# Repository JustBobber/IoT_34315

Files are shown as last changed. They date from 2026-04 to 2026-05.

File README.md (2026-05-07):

# Kom i gang med projektet

## Forudsætninger

- Python 3.3 eller nyere (tjek med `python --version` eller `python3 --version`)

---

## Opsætning af webserver

### 1. Klon projektet

```bash
git clone https://github.com/JustBobber/IoT_34315
cd IoT_34315
```

### 2. Opret virtuelt miljø

```bash
python3 -m venv .venv
```

### 3. Aktivér miljøet

**macOS / Linux:**
```bash
source .venv/bin/activate
```

**Windows:**
```bash
.venv\Scripts\activate
```

Du kan se at miljøet er aktivt når terminalen viser `(.venv)` foran din prompt.

### 4. Installér afhængigheder

```bash
pip install -r requirements.txt
```

## Opsætning af ESP'er
De to ESP'er skal have installeret firmware. Filerne ligger i ./firmware/esp/ESP8266_disp og ./firmware/esp/ESP32S3-Nano_controller til ESP8266 og ESP32S3 hhv.

### Installer firmware til ESP8266
Inden installation af firmwaren, kan det være nødvendigt at disconnecte RX-TX linket mellem ESP32 og ESP8266.
Åben filen ./firmware/esp/ESP8266_disp/ESP8266_disp.ino i Arduino IDE og installer den på ESP8266'eren.

Husk at forbind TX-RX linket igen hvis det er disconnected.

### Installer firmware til ESP32S3-Nano

Åben filen ./firmware/esp/ESP8266_disp/ESP32S3-Nano_controller.ino i Arduino IDE 
Opdater linje 45-48 til wifi netværk, password og serverens ip addresse:
```
/*
* Sørg for at starte serveren for at modtage og se dataene på localhost:5050.
*/
const char* WIFI_SSID = "<wifi name>";				    // update ssid
const char* WIFI_PASSWORD = "<wifi password>";			// update pw
const char* SERVER_BASE_URL = "http://<...ip...:5050";	// update ip
```
Når netværks instillernge er sat, installer koden på ESP32'eren.

---

# Daglig brug
For at køre projektet er der to ting du skal have kørende: webappen og ESP'erne.
Webappen står for backed og frontend. Der modtager data fra ESP, logger det i database og laver en hjemmeside hvor dataen kan ses.

ESP'erne står indsamler og sender data til webappen når en træning session er i gang. Ellers poller den serveren for at 
tjekke om der er en user logget ind da dette er et krav for at kunne påbegynde en træningssession. 

## Start server, webapp og populer database

### Aktiver virtual environment
Hver gang du åbner en ny terminal skal du aktivere miljøet igen:

```bash
source .venv/bin/activate   # macOS / Linux
.venv\Scripts\activate      # Windows
```

### Start webappen
```bash
python3 src/app.py
```
besøg siden: localhost:5050

Deaktivér venv når du er færdig:

```bash
deactivate
```

---

### Populer databasen: 
For at få noget data i databasen kør følgende script:

```bash
python3 src/seeds/alice_and_bob_seed.py
```
Det tilføjer et par users og generere et par sessions og noget data. 
Det kan køres flere gange hvis der ønskes mere data. 

### Slet databasen:
Det kan være nødvendigt/rart at slette database (training.db) den ligger her: src/training.db
```bash
rm src/training.db
```
Kør derefter seed scriptet igen for at få data i databasen.

---

## Start ESP's
Forbind det to ESP'er til power. 
OLED displayet skulle gerne vise teksten: 'GenStraek' 
og ToF sensoren skulle meget gerne gå i gang med at kalibrere ved at køre håndtaget op og derefter ned.
Hvis det er tilfældet, så bør det hele være sat op korrekt og klar til at blive brugt.

# Circuit diagram
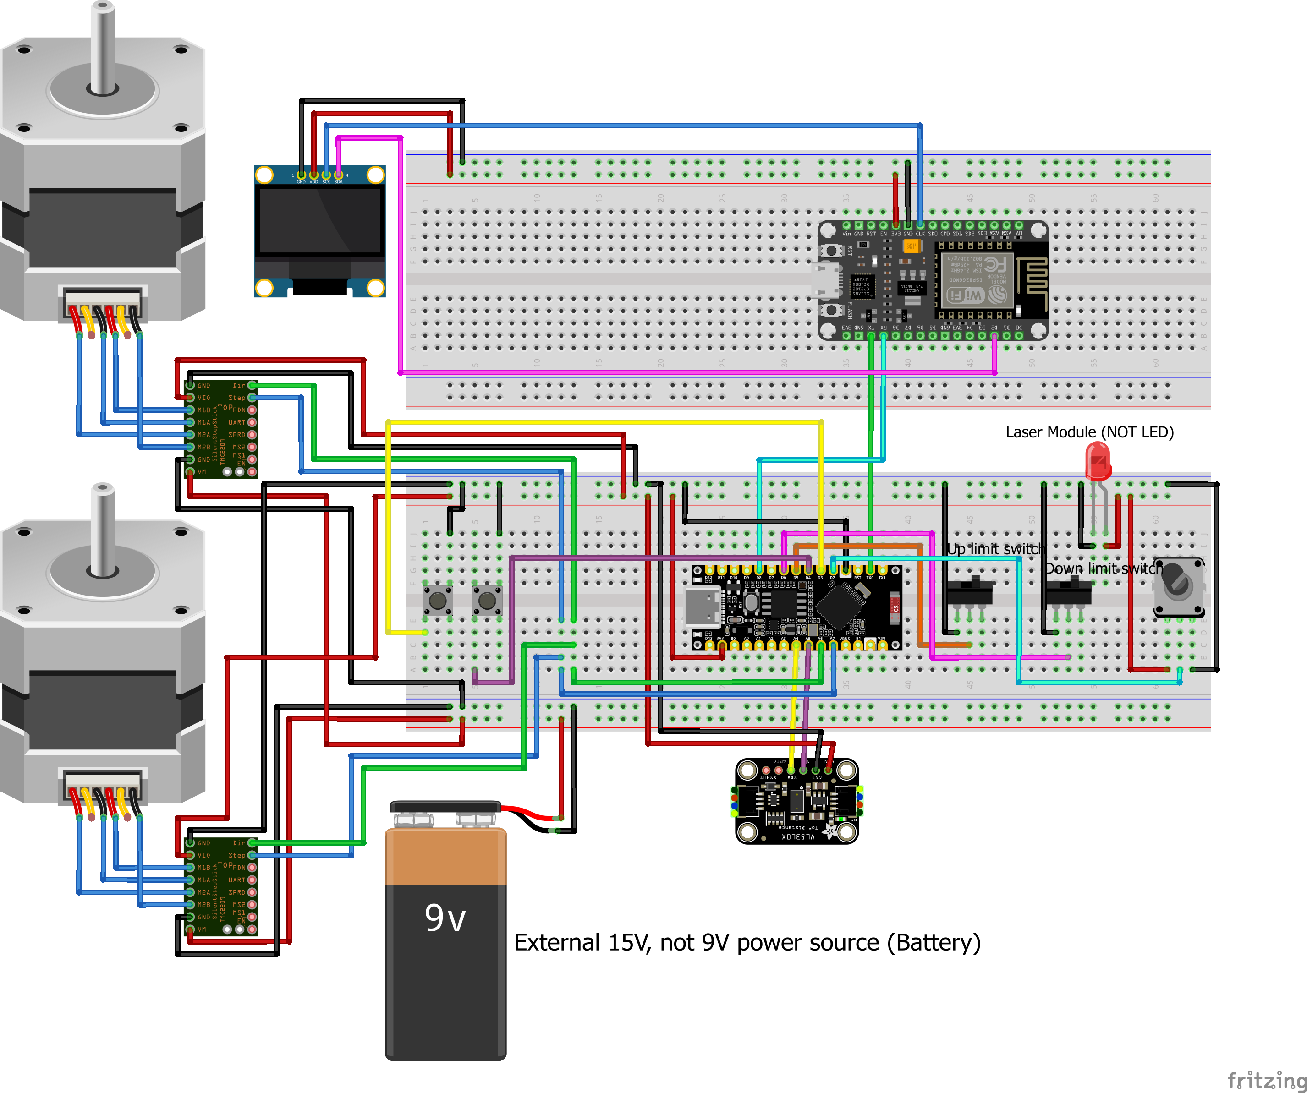
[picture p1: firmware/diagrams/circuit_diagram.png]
circuit diagram


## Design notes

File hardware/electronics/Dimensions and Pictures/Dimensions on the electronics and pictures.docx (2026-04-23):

Limit Switch

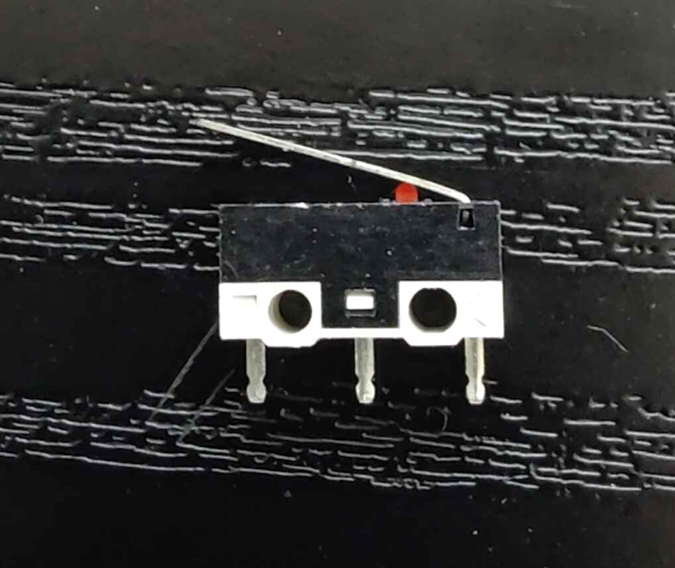
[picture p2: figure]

12.85 x 5.78mm

Motor Driver:

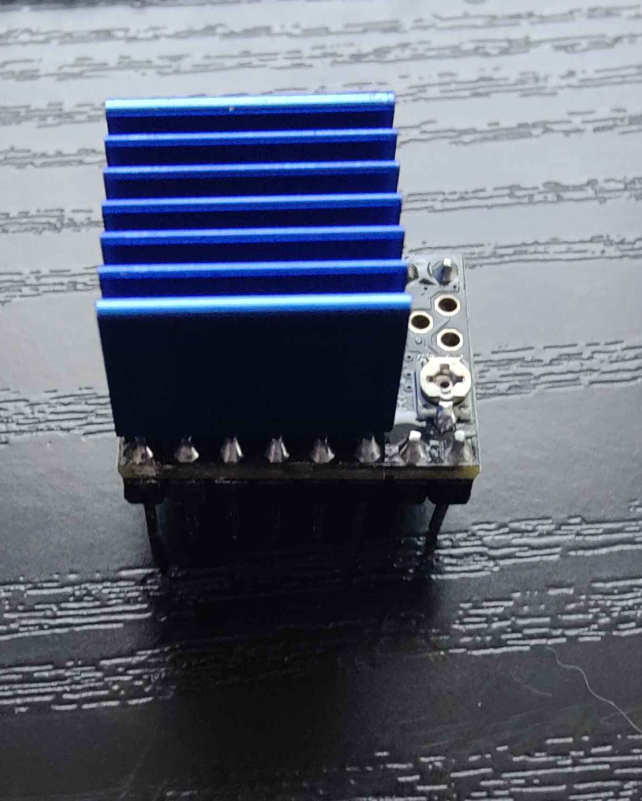
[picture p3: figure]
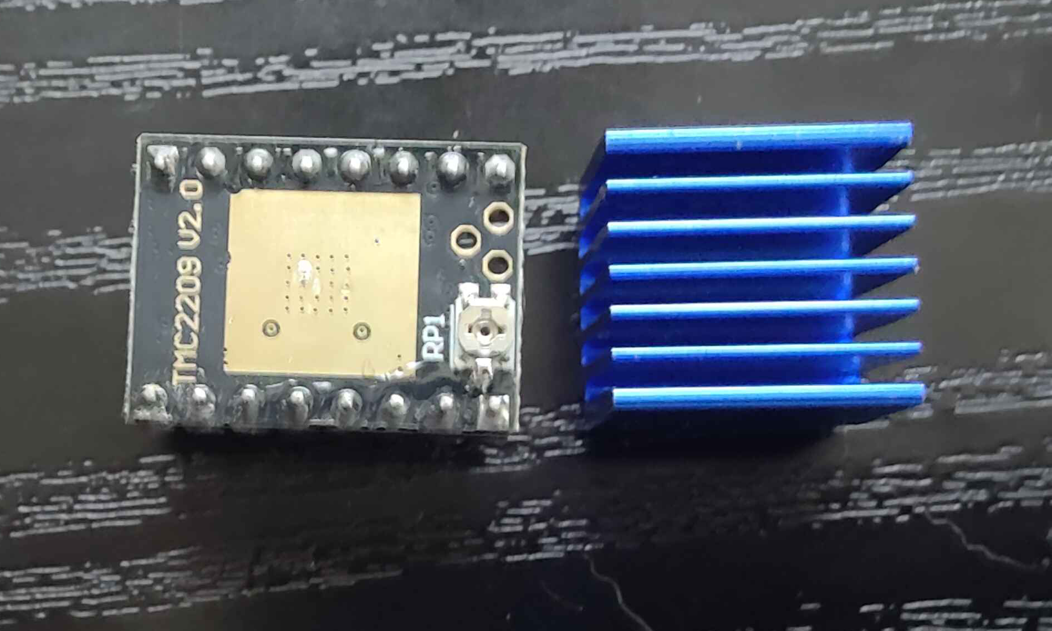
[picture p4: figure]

20.48 x 15mm

Laser:

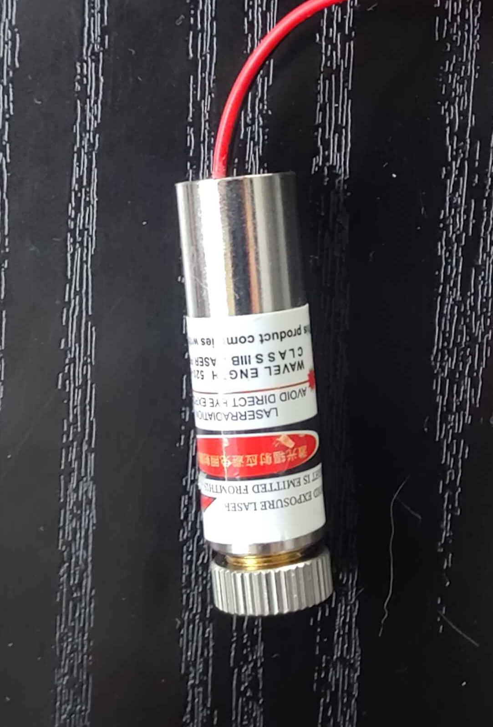
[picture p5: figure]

d = 12mm

h = 42.59mm

Pressure Gauge:

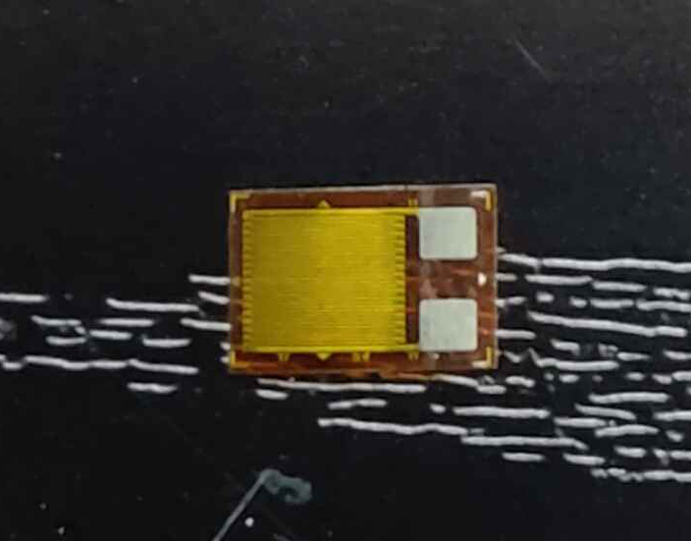
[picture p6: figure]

7.6 x 5.2mm

ToF Laser:

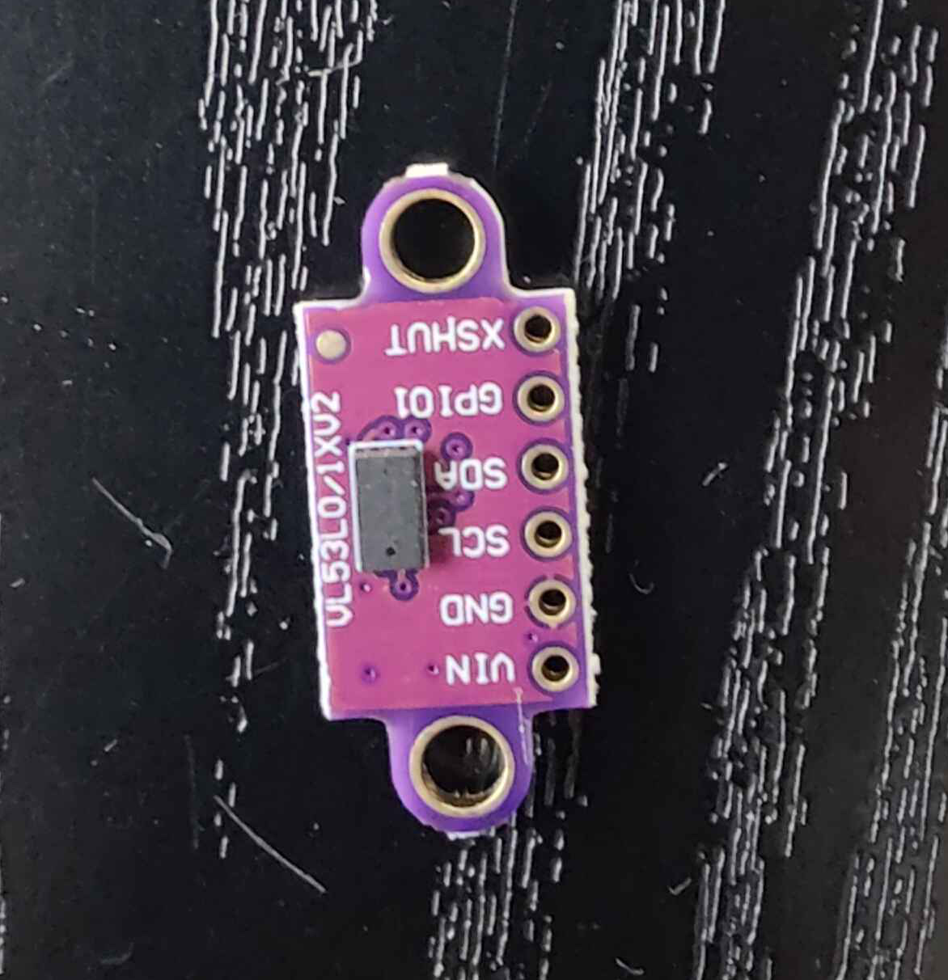
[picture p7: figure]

Dimensions without mounting holes:

15.64 x 12.29mm

Dimensions with mounting holes:

25.28 x12.29mm

PCB board:

Largest board:

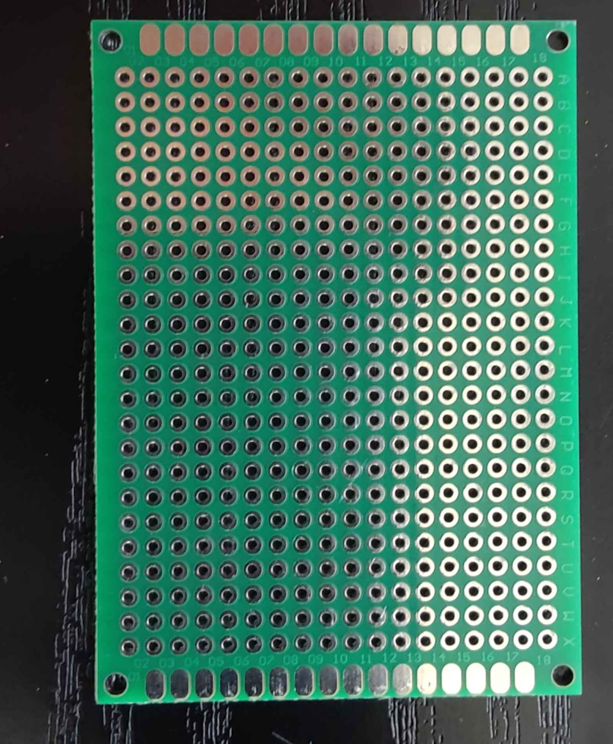
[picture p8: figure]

70.18 x 50.20mm

Medium board:

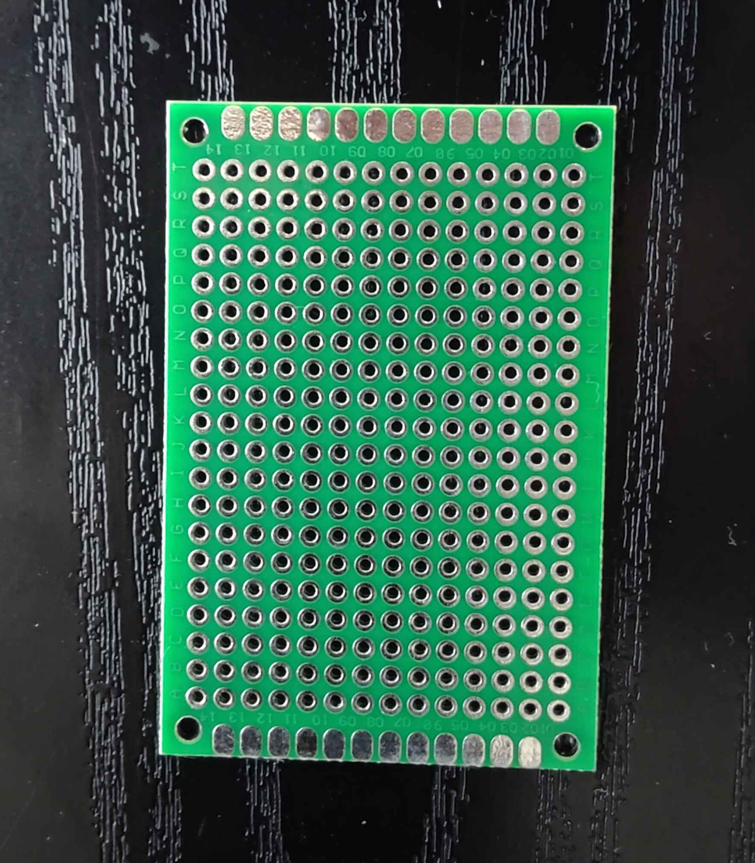
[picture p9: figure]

60 x 40.10mm

Battery Holder:

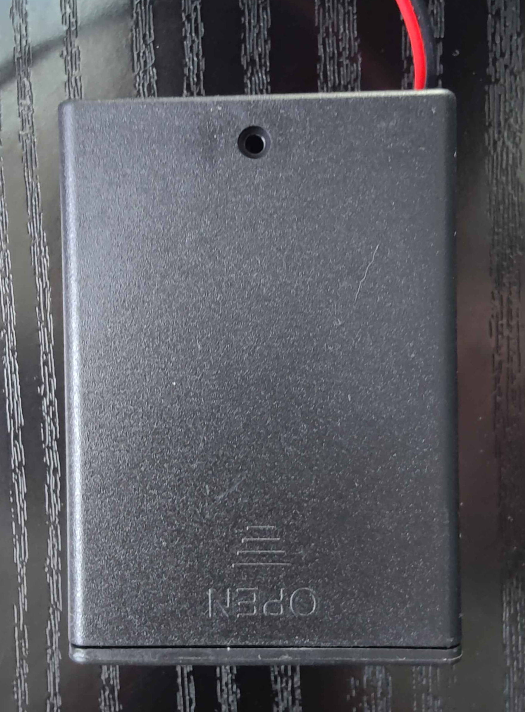
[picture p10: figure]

69 x 48.85mm

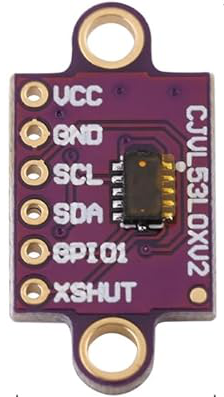
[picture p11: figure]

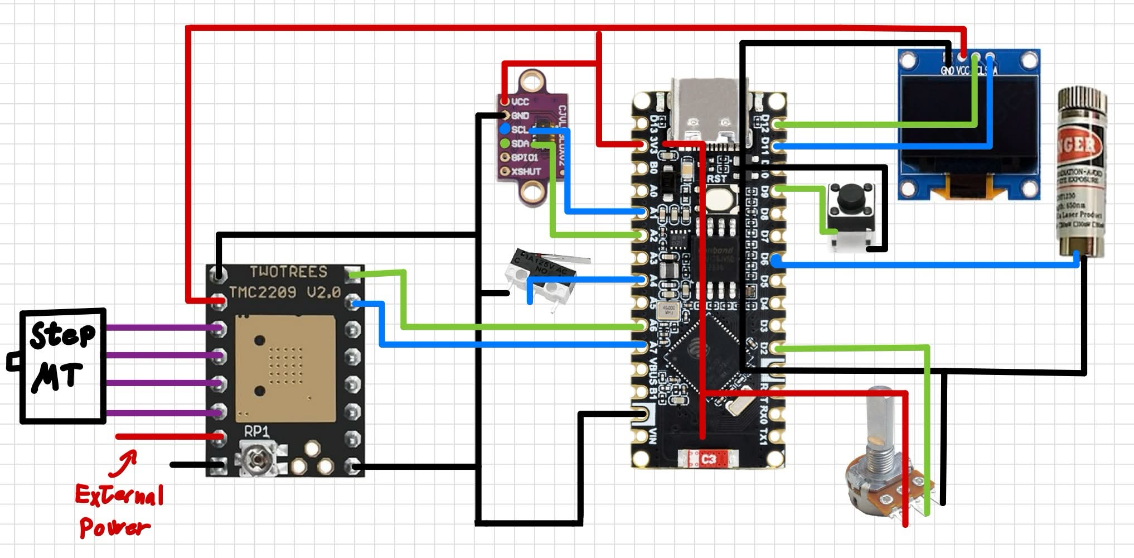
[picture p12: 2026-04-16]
hardware/electronics/schematics/1. iteration/1_iteration_sketch.jpg

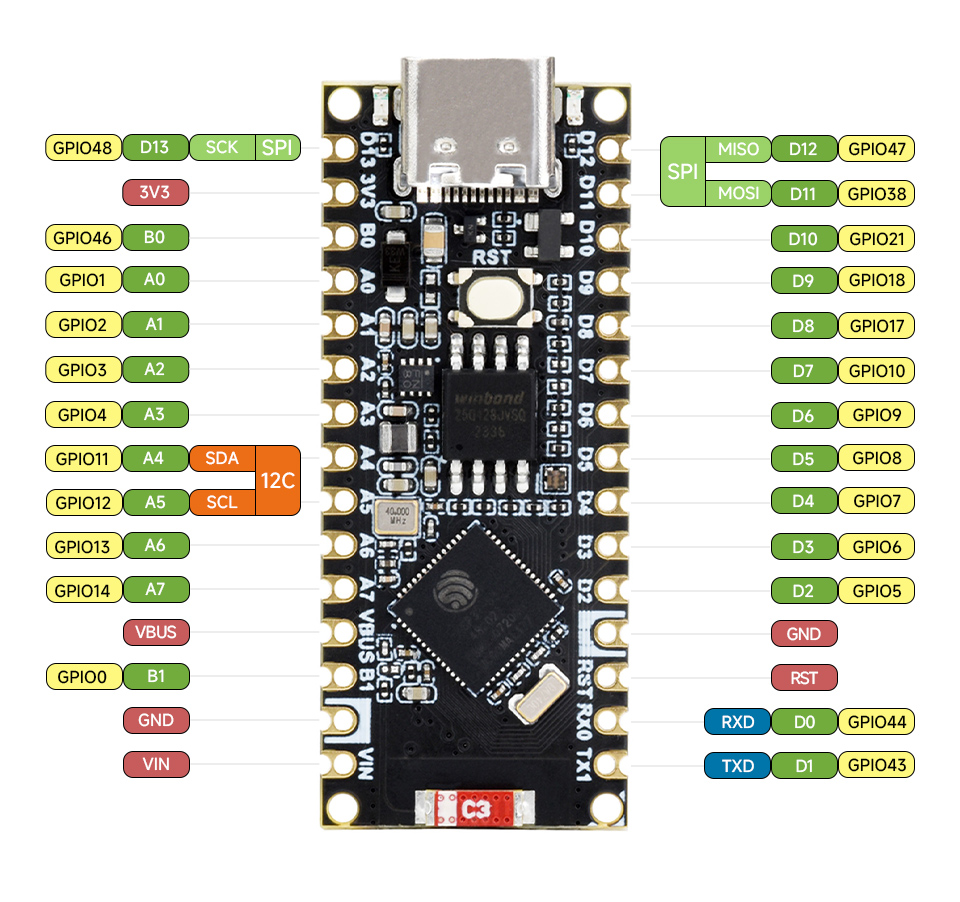
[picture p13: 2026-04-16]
hardware/electronics/schematics/1. iteration/esp32_s3.png

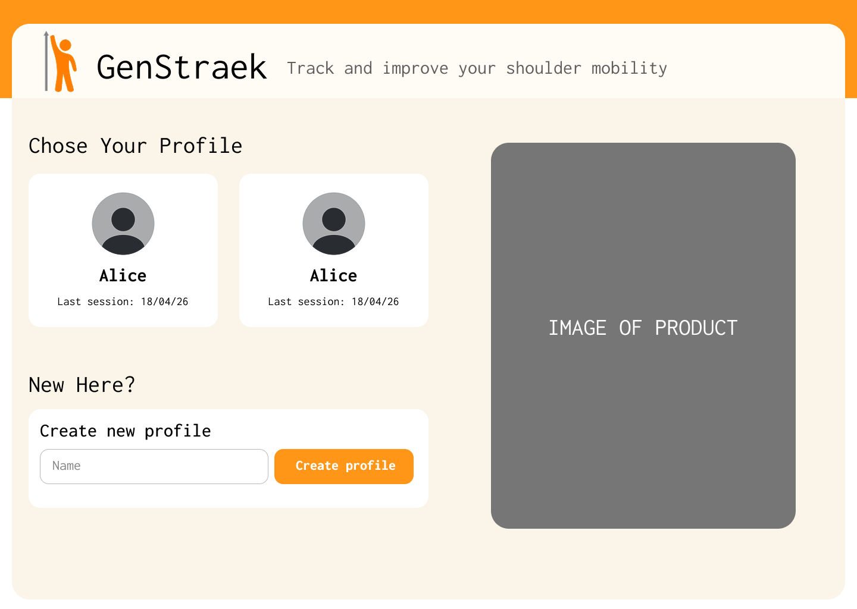
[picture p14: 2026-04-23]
project-management/wepapp-design/01-Home Page.png

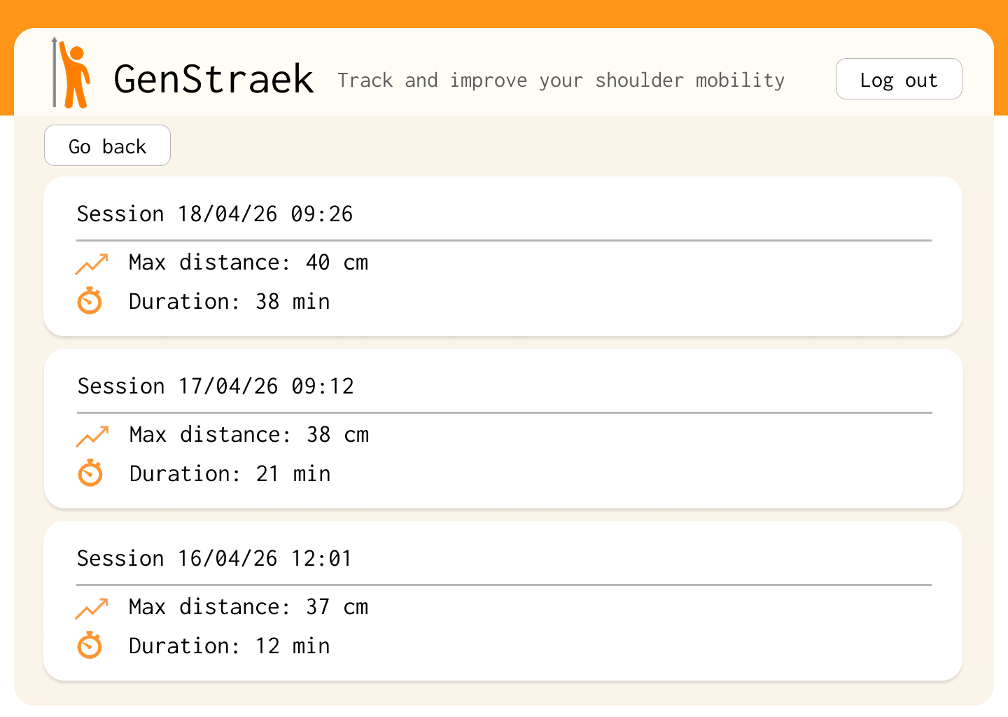
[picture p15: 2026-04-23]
project-management/wepapp-design/02-Past Sessions.png

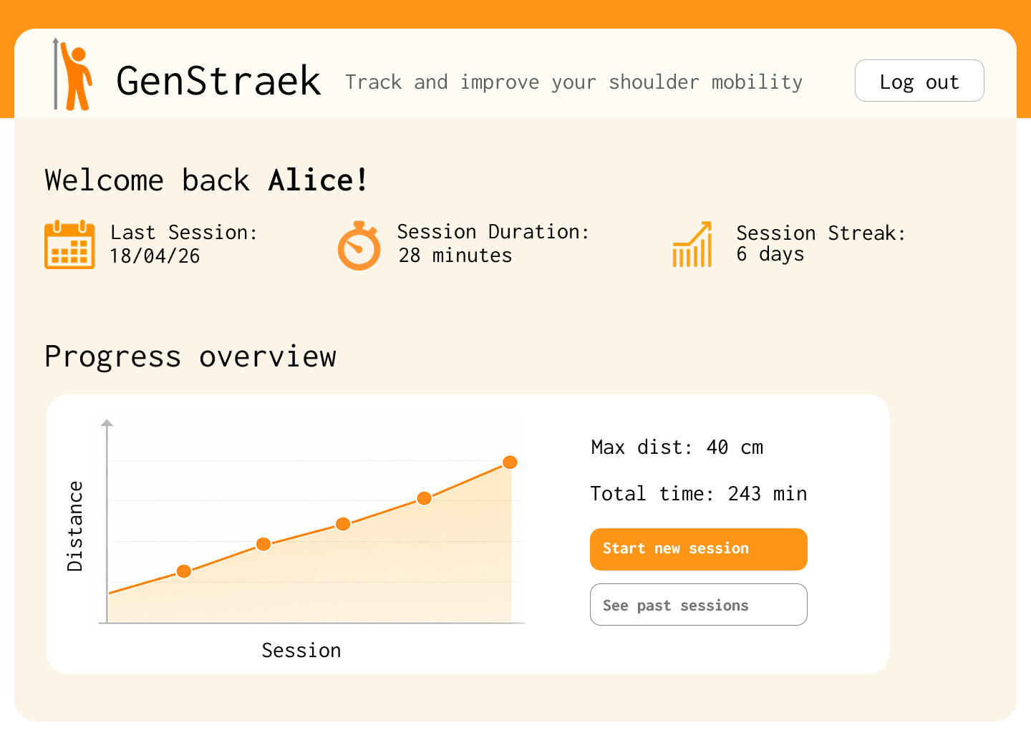
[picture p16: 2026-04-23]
project-management/wepapp-design/03-User Page.png

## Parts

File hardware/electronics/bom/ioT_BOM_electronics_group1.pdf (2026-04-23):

## Build of Materials: Electronics

- ESP32 (x2)
- OLED screen (x1)
- Connection Wires (as needed)
- Push buttons (x3)
- Potentiometer (x1)
- XT30 plug (x1)
- Battery Holder (x1)
- TMC 2209 V2 Stepper Motor Driver (x2)
- Lidar Sensor (x1)
- Strain Gauge (x1)
- Limit Switches (x2)
- PCB Board Kit (x1)
- Line Laser Module (x1)

1

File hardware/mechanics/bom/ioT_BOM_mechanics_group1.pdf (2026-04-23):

## Build of Materials: Mechanics

- Stepper motor (x2)
- Linear rails (x2)
- 3D filament (as needed)
- Magnets (as needed)
- GT2 belt 10mm (as neeeded)
- GT2 idler pulley 10mm (x8)
- GT2 16 teeth pulley 10mm (x2)
- 5mm steel rod (as needed)
- Threaded inserts: M3, M4, M5 (as needed)
- Bolts: M3, M4, M5 (as needed)

1

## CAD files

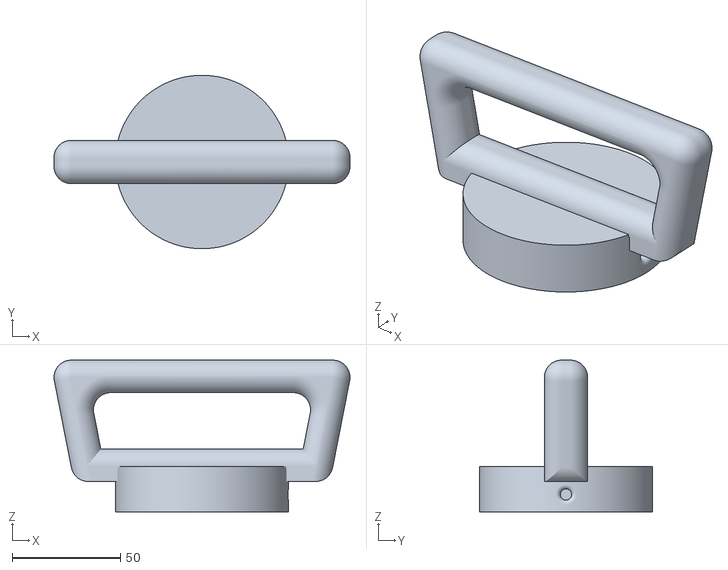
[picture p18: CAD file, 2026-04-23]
hardware/mechanics/cad/Basic Handle.stl
136.5 x 80.0 x 70.0

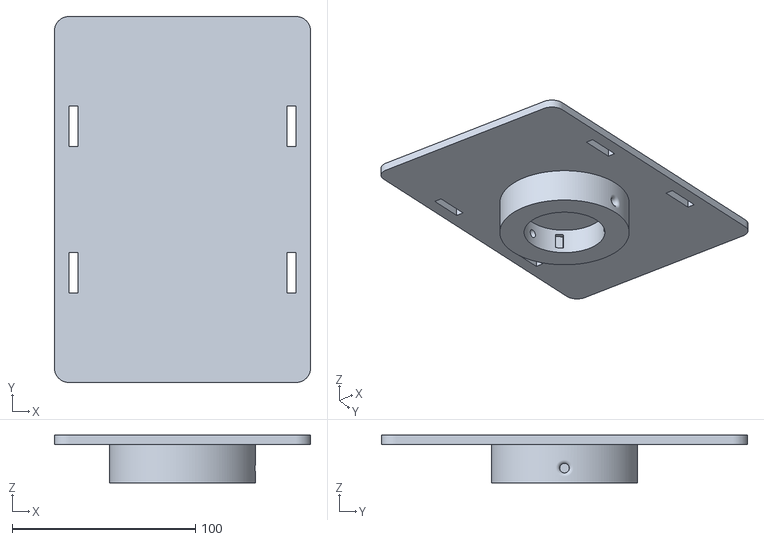
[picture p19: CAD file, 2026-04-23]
hardware/mechanics/cad/Flat Handle.stl
140.0 x 200.0 x 26.0

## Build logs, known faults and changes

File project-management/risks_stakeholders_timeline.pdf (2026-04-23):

## Project Management

## 1 Risks

The project is very ambitious given the available time frame, which creates the risk of the project wont be completed in time. Additionally, there is a need to acquire additional hardware and components. The supplementary hardware might not arrive in time or the project budget is insufficient to cover all extra expenses. Furthermore the group members may lack some of the skills or knowledge needed to successfully complete the project. None of the group members are healthcare professionals, which creates the risk of the final product not meeting the required standards for rehabilitating injuries, pain or reduced mobility in the shoulder.

## 2 Stakeholders

The main stakeholders are our group, since we are developing the product. Healthcare professionals working with shoulder rehabilitation are also important, as they would likely be the ones introducing and using the product in practice. Finally, people with shoulder injuries are key users, since they would use the product for rehabilitation. If the price is low enough, it could also be something individuals choose to buy and use at home.

## 3 Timeline

Project Step | Week 8 | Easter | Week 9 | Week 10 | Week 11 | Week 12 | Week 13

Project planning
Concept development
Prototype 1
ESP32 Programming
Mechanics
Electronics
Database Backend
Prototype 2
Final Product
Webapp
Report writing
Presentation preparation

1

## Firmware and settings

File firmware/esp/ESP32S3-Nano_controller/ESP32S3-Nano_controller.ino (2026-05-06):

#include <WiFi.h>
#include <HTTPClient.h>
#include <Arduino.h>
#include <Wire.h>
#include <VL53L0X.h>


// ___ hardware setup ___
const int START_BUTTON_PIN = 6;
const int STOP_BUTTON_PIN = 7;

const int LIMIT_SWITCH_TOP_PIN = 8;
const int LIMIT_SWITCH_BOTTOM_PIN = 9;

const int POTENTIOMETER_PIN = 5;

const int TOF_SDA_PIN = 11;
const int TOF_SCL_PIN = 12;

const int STEPPER_STEP_PIN = 14;
const int STEPPER_DIR_PIN = 13;
const int STEPPER_ENABLE_PIN = 10;
const int STEP_DELAY_US = 100;


const int TX_PIN = 17;
const int RX_PIN = 16;
HardwareSerial mySerial(2);

VL53L0X tof;

// ___ sensor variable ___
bool MOTOR_UP = false;
bool MOTOR_DOWN = true;

int difficulty = 0; // mapping fra potmeter value

uint16_t tofDistance = 0;

uint16_t tofBottomDistance; // afstanden til tof sensoren når den er i bund.
uint16_t tofTopDistance;

/*
* Sørg for at starte serveren for at modtage og se dataene på localhost:5050.
*/
const char* WIFI_SSID = "Livswifi";				    // update ssid
const char* WIFI_PASSWORD = "liv120701";			// update pw
const char* SERVER_BASE_URL = "http://172.20.10.8:5050";	// update ip

const int SECOND_IN_MILLIS = 1000;

// ___ data sending consts and variables ___
// Data til server
const unsigned long TCP_MESSAGE_INTERVAL = 5 * SECOND_IN_MILLIS; // Hvor ofte der sendes data til serveren, hvert 20 sekund. TODO: opdater efter behov.
unsigned long last_tcp_message_send_time = millis();
// poller server for at tjekke om der er user logget ind
const unsigned long POLL_INTERVAL = 5 * SECOND_IN_MILLIS;  // poll hvert 5. sekund
unsigned long last_poll_time = 0;
// sender update til display
unsigned long uart_transmit_timer = millis();
unsigned long UART_TRANSMIT_DELAY = 1000; // updaterer display hvert 100. millisekund.

// ___ session variables ___
bool session_in_progress = false;
uint16_t max_distance = 0; // kun til display
String session_uuid = "";

// ___ user consts and variables ___
bool user_logged_in = false;


void updateDisplay(String tekst, int size = 10);

void setup() {
    Serial.begin(115200);
    mySerial.begin(9600, SERIAL_8N1, RX_PIN, TX_PIN); // UART2


    // tryk knapper og kontakter
    pinMode(START_BUTTON_PIN, INPUT_PULLUP);
    pinMode(STOP_BUTTON_PIN, INPUT_PULLUP);
    pinMode(LIMIT_SWITCH_BOTTOM_PIN, INPUT_PULLUP);
    pinMode(LIMIT_SWITCH_TOP_PIN, INPUT_PULLUP);

    // motor setup
    pinMode(STEPPER_STEP_PIN, OUTPUT);
    pinMode(STEPPER_DIR_PIN, OUTPUT);
    pinMode(STEPPER_ENABLE_PIN, OUTPUT);

    digitalWrite(STEPPER_ENABLE_PIN, LOW);
    digitalWrite(STEPPER_STEP_PIN, LOW);
    digitalWrite(STEPPER_DIR_PIN, LOW);

    // time of flight sensor
    Wire.begin(TOF_SDA_PIN, TOF_SCL_PIN, 400000);
    tof.setTimeout(500);
    tof.init(); // TODO: afgør om der skal være et tjek af om init gik godt.
    tof.startContinuous();

    calibrateTofSensor();

    // connecter til wifi
    Serial.print("Forbinder til WiFi");
    WiFi.begin(WIFI_SSID, WIFI_PASSWORD);
    while (WiFi.status() != WL_CONNECTED) {
        delay(500);
        Serial.print(".");
        updateDisplay("No network \nconnection..");
    }
    Serial.println("\nForbundet! IP: " + WiFi.localIP().toString());
}

void loop() {

    pollUserStatus(); // Checks if a user is logged in.

    difficulty = map(analogRead(POTENTIOMETER_PIN), 0, 4095, 0, 10);
    tofDistance = readTofSensor() - tofBottomDistance + 15; // tof.readRangeContinuousMillimeters(); // TODO: opdater med fejlen fra kalibrationen!
    if (tofDistance > 1000) {
        tofDistance = 0;
    }

    max_distance = max(tofDistance, max_distance);

    // TIL TEST
    // Serial.print("buttom pin:");
    // Serial.println(digitalRead(LIMIT_SWITCH_BOTTOM_PIN));
    // Serial.print("top pin:");
    // Serial.println(digitalRead(LIMIT_SWITCH_TOP_PIN));
    // Serial.print("distance: ");
    // Serial.println(String(tofDistance));
    // delay(500);

    if (!session_in_progress)
        if (!user_logged_in) {
            updateDisplay("User not logged in");
        } else {
            updateDisplay("User is logged in;" "Ready to start");
        }

    // Start button
    if (digitalRead(START_BUTTON_PIN) == LOW && not session_in_progress) {
        session_uuid = generateUUID();
        max_distance = 0;  // resetter max distance ved start af ny session.
        if (startSession(session_uuid) == true) {
            session_in_progress = true;
            updateDisplay("Starting session");
        }
        else {
            updateDisplay("Log in first!");
        }
    }

    // Stop button
    if (digitalRead(STOP_BUTTON_PIN) == LOW && session_in_progress) {
        bool result = stopSession(session_uuid);
        session_in_progress = !result;

        updateDisplay(
            "Session has ended;;"
            "Max distance for session:;"
            + String((float)max_distance / 10) + " cm"
        );

        delay(10000); // bliv på skærmen i 10 sekunder
    }

    if (session_in_progress == true) {

        runMotor(difficulty);

        if ((millis() - TCP_MESSAGE_INTERVAL) > last_tcp_message_send_time) {

            last_tcp_message_send_time = millis();

            // if (isnan(tofDistance)) { // virker kun til floats eller doubles..
            if (tof.timeoutOccurred()) {
                updateDisplay("Fejl: Kunne ikke læse afstands sensor!");
            } else {
                //updateDisplay("Distance: " + String((float)tofDistance / 10) + " cm");
                bool sendDataResult = send_session_data();

                if (sendDataResult == true) {
                    updateDisplay(
                        "Session in progress;"
                        "Distance: " + String((float)tofDistance / 10) + " cm;"
                        "Max distance: " + String((float)max_distance / 10) + " cm;"
                        "Difficulty: " + String(difficulty)
                    );
      
                } else {
                    updateDisplay("Kunne ikke sende data!");
                }
            }
        }
    }
}


// ___ Helper functions ___

/*
* generates an uuid for the current training session such that we can make sure
* it is the esp's stop button that starts and ends a given training session.
*
* return String: uuid for training session.
*/
String generateUUID() {
  char uuid[37];
  snprintf(uuid, sizeof(uuid),
           "%08x-%04x-4%03x-%04x-%012llx",
           (uint32_t)esp_random(),
           (uint16_t)esp_random(),
           (uint16_t)(esp_random() & 0x0FFF),
           (uint16_t)((esp_random() & 0x3FFF) | 0x8000),
           ((uint64_t)esp_random() << 32) | esp_random());
  return String(uuid);
}

/*
* initiate a new training session. The server checks that a user is logged in for the
* given training session.
*
* return boolean: true if a user is logged in to the webapp otherwise false.
*/
bool startSession(String uuid) {

    if (WiFi.status() != WL_CONNECTED) {
        return false;
    }

    WiFiClient client;
    HTTPClient http;
    http.begin(client, String(SERVER_BASE_URL) + "/start_session");
    http.addHeader("Content-Type", "application/json");

    String body = "{\"session_uuid\":\"" + uuid + "\"}";

    int svar = http.POST(body);
    http.end();

    if (svar == 200) {
        return true;
    } else {
        return false;
    }
}

/*
* sends data to the server for the current training session. The data includes distance, difficulty and session uuid.
*/
bool send_session_data() {

    if (WiFi.status() != WL_CONNECTED) {
        return false;
    }

    WiFiClient client;
    HTTPClient http;
    http.begin(client, String(SERVER_BASE_URL) + "/data");
    http.addHeader("Content-Type", "application/json");

    String body = "{\"distance\":" + String((float)tofDistance / 10, 1)
                + ",\"session_uuid\":\"" + session_uuid + "\""
                + ",\"difficulty\":" + String((float)difficulty / 10, 1) + "}";

    int svar = http.POST(body);
    http.end();
    // updateDisplay(svar == 200 ? "Sendt OK" : "Fejl: " + String(svar));
    if (svar == 200) {
        return true;
    } else {
        return false;
    }
}


/*
* Stops an ongoing training session.
*
* return boolean: true if training was not in progress or stopped.
*                 false if there was no connection to wifi or server responds with err.
*/
bool stopSession(String uuid) {

    if (session_in_progress == false) {
        return true; // Hvis der ikke er en træningssession i gang tælle dette som success.
    }

    if (WiFi.status() != WL_CONNECTED) {
        return false;
    }

    WiFiClient client;
    HTTPClient http;
    http.begin(client, String(SERVER_BASE_URL) + "/end_session");
    http.addHeader("Content-Type", "application/json");

    String body = "{\"session_uuid\":\"" + uuid + "\"}";

    int svar = http.POST(body);
    http.end();

    if (svar == 200) {
        return true;
    } else {
        return false;
    }
}

/*
*  Sends a request to the server at every poll_interval times to check if there is a user that is logged in.
*  The state of user_logged_in then gets updated.
*/
void pollUserStatus() {
    if (millis() - last_poll_time < POLL_INTERVAL) {
        return;
    }
    last_poll_time = millis();

    if (WiFi.status() != WL_CONNECTED) {
        return;
    }

    WiFiClient client;
    HTTPClient http;
    http.begin(client, String(SERVER_BASE_URL) + "/current_user");
    int httpCode = http.GET();

    if (httpCode == 200) {
        user_logged_in = true;
        Serial.println("Bruger logget ind");
    } else {
        user_logged_in = false;
        Serial.println("Ingen bruger logget ind");
    }
    http.end();
}

void updateDisplay(String tekst, int fontsize) {

    String stringToSend = tekst;
    if ((millis() - UART_TRANSMIT_DELAY) > uart_transmit_timer) {
        // TODO: implementer TX funktionalitet til String tekst
        mySerial.println(stringToSend);
        Serial.println(stringToSend);

        uart_transmit_timer = millis();
    }
}

/*
* Helper funktion to read from time of flight sensor
* Return: distance in millimeters
*/
uint16_t readTofSensor() {
    uint16_t tof_distance = tof.readRangeContinuousMillimeters();

    return tof_distance;
}

/*
* Running the motor to the top and bottom limit switch to calibrate the time of fligth sensor with respect to the
* limit swithces.
*/
void calibrateTofSensor() {
    Serial.println("calibrating ToF");
    digitalWrite(STEPPER_DIR_PIN, MOTOR_UP);
    delayMicroseconds(10);

    while(digitalRead(LIMIT_SWITCH_TOP_PIN) == HIGH) {
        digitalWrite(STEPPER_STEP_PIN, HIGH);
        delayMicroseconds(STEP_DELAY_US);
        digitalWrite(STEPPER_STEP_PIN, LOW);
        delayMicroseconds(STEP_DELAY_US);
    }
    tofTopDistance = readTofSensor();
    Serial.println("top limit switch activated");
    Serial.print("Top pos: ");
    Serial.println(tofTopDistance);

    digitalWrite(STEPPER_DIR_PIN, MOTOR_DOWN);
    delayMicroseconds(10);

    while(digitalRead(LIMIT_SWITCH_BOTTOM_PIN) == HIGH) {
        digitalWrite(STEPPER_STEP_PIN, HIGH);
        delayMicroseconds(STEP_DELAY_US);
        digitalWrite(STEPPER_STEP_PIN, LOW);
        delayMicroseconds(STEP_DELAY_US);
    }
    tofBottomDistance = readTofSensor();
    Serial.println("bottom limit switch activated");
    Serial.print("Bottom pos: ");
    Serial.println(tofBottomDistance);

    digitalWrite(STEPPER_ENABLE_PIN, HIGH);
}

/*
* Run the motor down based on difficulty
*/
void runMotor(int difficulty) {
    return; // TODO: Remove me!
    if (difficulty == 0) {
        return;
    }
    if (digitalRead(LIMIT_SWITCH_BOTTOM_PIN) == LOW) {
        return;
    }

    int stepDelay = map(difficulty, 1, 10, 1000, 100);
    int steps = map(difficulty, 1, 10, 5, 50);

    digitalWrite(STEPPER_ENABLE_PIN, LOW);

    for (int i = 0; i < steps; i++) {
        if (digitalRead(LIMIT_SWITCH_BOTTOM_PIN) == LOW) break;

        digitalWrite(STEPPER_STEP_PIN, HIGH);
        delayMicroseconds(stepDelay);
        digitalWrite(STEPPER_STEP_PIN, LOW);
        delayMicroseconds(stepDelay);
    }

    digitalWrite(STEPPER_ENABLE_PIN, HIGH);
}

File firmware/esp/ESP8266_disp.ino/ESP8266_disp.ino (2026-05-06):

#include <Arduino.h>
#include <Wire.h>
#include "SH1106Wire.h"

// ESP8266 I2C pins:
// SDA = D2 = GPIO4
// SCL = D1 = GPI14
SH1106Wire display(0x3c, 4, 14);

String incoming = "";
String currentText = "";


String receiveMessage() {
  while (Serial.available()) {
    char c = Serial.read();

    if (c == '\n') {
      String msg = incoming;
      incoming = "";
      msg.trim();
      return msg;
    } else {
      incoming += c;
    }
  }

  return "";
}

void setup() {
  Serial.begin(9600);      // Must match ESP32 UART baud rate
  Serial.setTimeout(50);

  Wire.begin(4, 5); //TODO: change to (4,14)

  display.init();
  display.clear();
  display.setTextAlignment(TEXT_ALIGN_LEFT);

  drawScreen("GenStraek", 24);
}

void loop() {
  String msg = receiveMessage();
  msg.replace(";", "\n");

  if (msg.length() > 0) {
    Serial.println(msg);
    currentText = msg;   // store message
    drawScreen(currentText, 13);
    Serial.println("----");
  }
}

void drawScreen(String tekst, int fontsize) {
    // vi kan generere egne fonts her:
    //  https://oleddisplay.squix.ch/
    display.clear();
    if (fontsize >= 24) {
        display.setFont(ArialMT_Plain_24);
    }
    else if (fontsize >= 16) {
        display.setFont(ArialMT_Plain_16);
    }
    else {
        display.setFont(ArialMT_Plain_10);
    }
    display.drawString(0, 0, tekst);
    display.display();
}

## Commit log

2026-04-16 removed pressure from db and session view
2026-04-16 added debug prints and proof of concept esp file
2026-04-16 Added BOM for machanics and electronics
2026-04-16 Added handle CAD files and stakeholder files
    [Basic Handle.stl, Flat Handle.stl]
2026-04-18 implemented start and stop buttons and funcions, and user polling in esp
2026-04-23 TMC and TOF sensor test
2026-04-30 Communication betweeen esp32 and esp8266
2026-05-04 Added Motor enable pin
2026-05-04 updated motor code
2026-05-06 Små bugs i ESP8266 kode
    [ESP8266_disp.ino]
2026-05-06 fixed minor bugs in display code
    [ESP8266_disp.ino]
2026-05-07 added circuit diagram to readme
